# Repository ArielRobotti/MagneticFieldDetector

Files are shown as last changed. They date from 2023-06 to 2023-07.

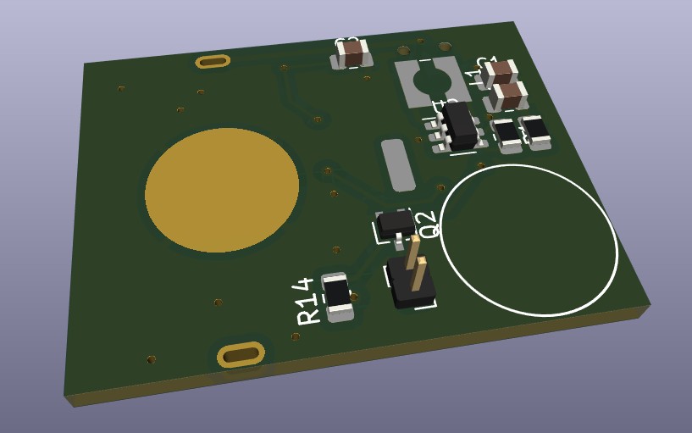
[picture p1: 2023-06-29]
images/ScreenShot_20230629164734.jpeg

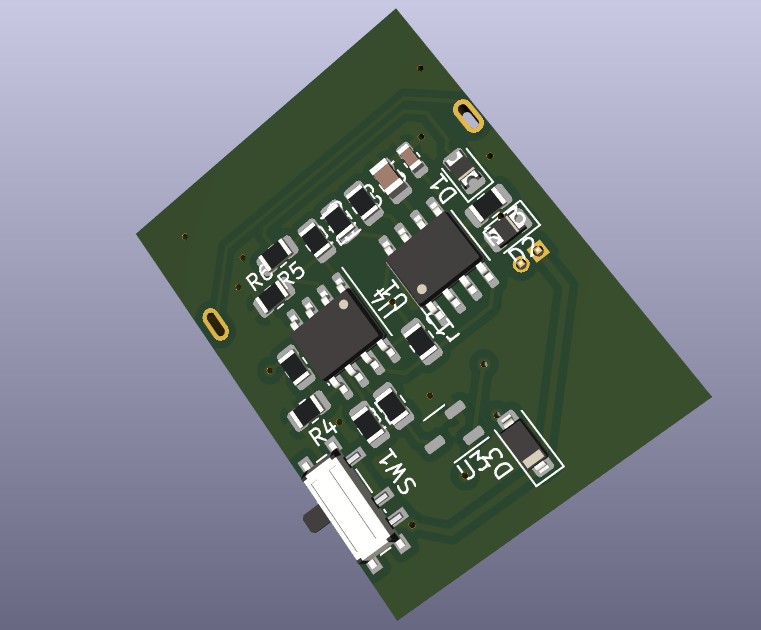
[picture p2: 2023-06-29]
images/ScreenShot_20230629164644.jpeg

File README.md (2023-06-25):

# Magnetic Field Polarity Detector 
## This device is designed for use in the field of magical arts.

## Description
The Magnetic Field Polarity Detector is a compact device designed to detect the presence of a magnetic field and indicate its polarity through vibrations. When the device is exposed to a north-to-south magnetic field, it will vibrate intermittently, while a south-to-north magnetic field will cause continuous vibrations.

## Schematic Design and Simulation in Multisim 14
The chosen design is based on the implementation of a linear Hall sensor, AH49E, which provides an output voltage proportional to the intensity of the magnetic field. The sensor outputs a voltage within specific thresholds depending on the magnetic field intensity. This voltage is then processed by comparators to activate the vibration motor accordingly.

### Design Adaptations
To accommodate the power supply requirements of the circuit components, an additional boost converter stage was included. This stage provides a stable 5V output from the 3V battery. The motor is directly powered from the 3V line to prevent feedback into the 5V line.

## Usage
1. Ensure that the device is turned off before use.
2. Insert a 3V battery into the battery holder.
3. Turn on the device using the power switch.
4. Hold the Magnetic Field Polarity Detector near the target area.
5. Observe the vibration patterns:
- Intermittent vibrations indicate the presence of a magnetic field in the south-to-north direction.
- Continuous vibrations indicate the presence of a magnetic field in the north-to-south direction.
6. Move the detector away from the proximity of the magnetic object to stop the vibrations.
7. Turn off the device when not in use to conserve battery life.
  
## Specifications
- Dimensions: 25mm x 30mm
- Power Supply: 3V battery (included)
- Power Switch: On/Off control

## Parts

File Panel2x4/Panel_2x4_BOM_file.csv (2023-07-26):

Comment | Designator | Footprint | LCSC Part Number
3Volts | BT1 | Batery Holder:cr1616
Motor_DC | M1 |  | C2685990
4u7 | C1 | C0805 | C2835535
4u7 | C2 | C0805 | C2835535
4u7 | C3 | C0805 | C2835535
4u7 | C5 | C0805 | C2835535
100n | C4 | 0603 | C342854
1N4148 | D1 | SOD-123 | C917030
1N4148 | D2 | SOD-123 | C917030
SS14HE | D3 | SOD-123HE | C4749020
4.7uH | L1 | SMD | 4x4mm | C5120868
BSS214NW | Q2 | SOT-323 | C3247496
910k | R1 | R0805 | C3016845
910k | R13 | R0805 | C3016845
100K | R2 | R0805 | C3017875
120k | R3 | R0805 | C268319
120k | R6 | R0805 | C268319
100k | R4 | R0805 | C3017875
100k | R5 | R0805 | C3017875
10k | R7 | R0805 | C3016734
10k | R8 | R0805 | C3016734
10k | R11 | R0805 | C3016734
10k | R12 | R0805 | C3016734
1k | R9 | R0805 | C3017842
22k | R10 | R0805 | C2889807
10 | R14 | R0805 | C101420
On | SW1 | SW_SPDT_PCM12 | C493292
SE555D | U1 | SO:SOIC-8 | C7593
TPS61070 | U2 | SOT-23-6 | C9841
49E Hall | U3 | SOT-23 | C85573
LM393 | U4 | SO:SOIC-8 | C2931601

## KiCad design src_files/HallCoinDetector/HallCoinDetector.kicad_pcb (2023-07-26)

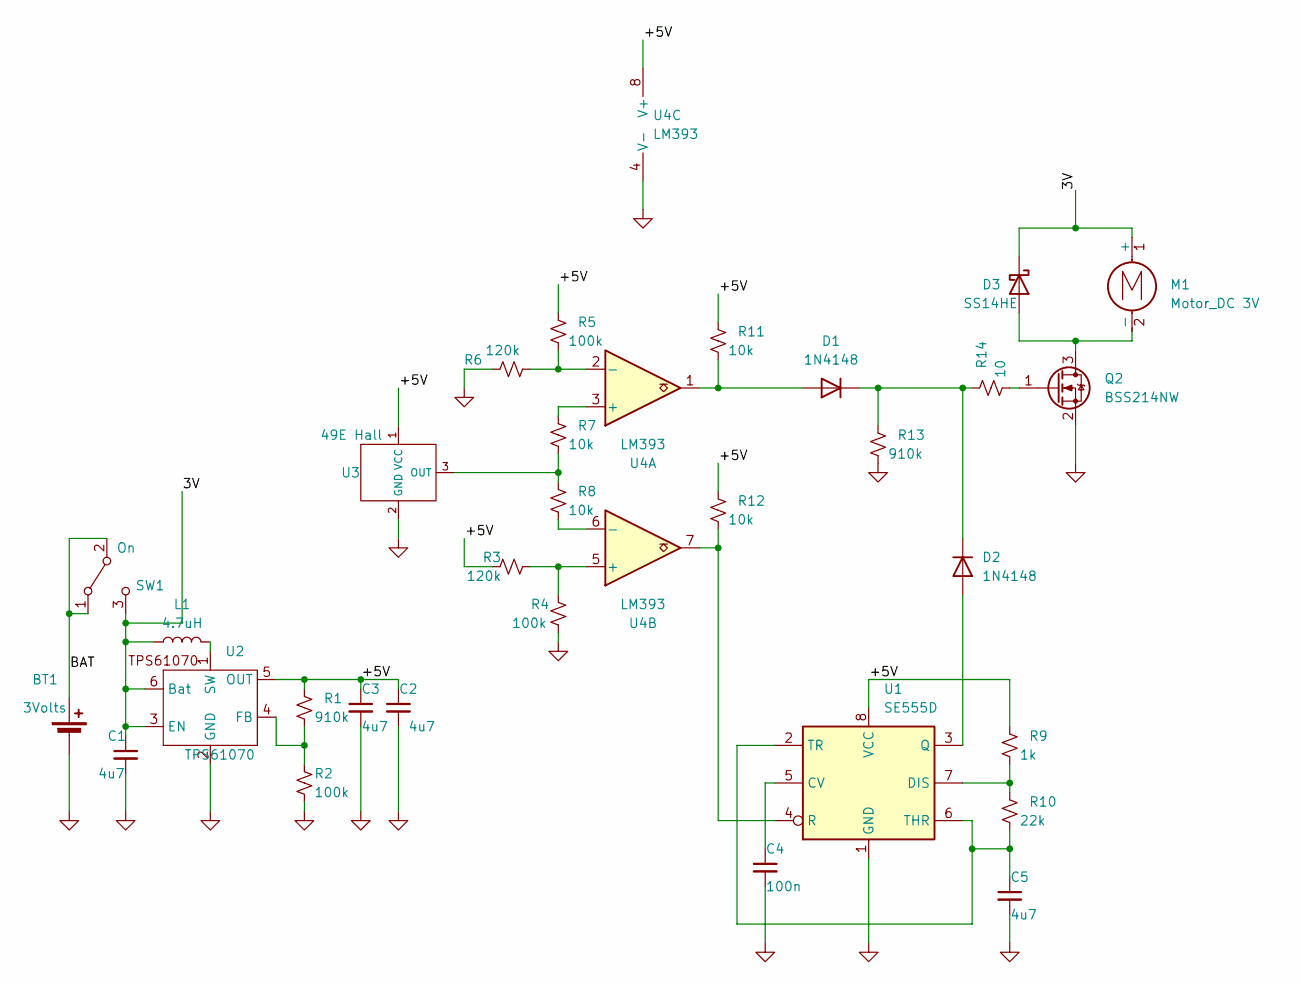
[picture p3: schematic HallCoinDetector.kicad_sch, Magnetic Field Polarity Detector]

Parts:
BT1: 3Volts; cr1616
C1, C2, C3, C5: 4u7; C_0805_2012Metric
C4: 100n; C_0603_1608Metric
D1, D2: 1N4148; D_SOD-123
D3: SS14HE; D_PowerDI-123
L1: 4.7uH; L_Wuerth_WE-TPC-3816
M1: Motor_DC 3V; PinHeader_1x02_P1.27mm_Vertical
Q2: BSS214NW; SOT-323_SC-70
R1, R13: 910k; R_0805_2012Metric
R2, R4, R5: 100k; R_0805_2012Metric
R3, R6: 120k; R_0805_2012Metric
R7, R8, R11, R12: 10k; R_0805_2012Metric
R9: 1k; R_0805_2012Metric
R10: 22k; R_0805_2012Metric
R14: 10; R_0805_2012Metric
SW1: On; SW_SPDT_PCM12
U1: SE555D; SOIC-8_3.9x4.9mm_P1.27mm
U2: TPS61070; SOT-23-6
U3: 49E Hall; SOT-23-3
U4: LM393; SOIC-8_3.9x4.9mm_P1.27mm

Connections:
/3V: C1.1, D3.1 (K), L1.1, M1.1 (+), SW1.3 (C), U2.3 (EN), U2.6 (Bat)
/+5V: C2.1, C3.1, R1.1, R3.1, R5.1, R9.1, R11.1, R12.1, U1.8 (VCC), U2.5 (OUT), U3.1 (VCC), U4.8 (V+)
/BAT: BT1.1 (+), SW1.1 (A), SW1.2 (B)
GND: BT1.2 (-), C1.2, C2.2, C3.2, C4.2, C5.2, Q2.2 (S), R2.2, R4.2, R6.1, R13.2, U1.1 (GND), U2.2 (GND), U3.2 (GND), U4.4 (V-)
unnamed: D1.2 (A), R11.2, U4.1
unnamed: D1.1 (K), D2.1 (K), R13.1, R14.1
unnamed: D2.2 (A), U1.3 (Q)
unnamed: D3.2 (A), M1.2 (-), Q2.3 (D)
unnamed: Q2.1 (G), R14.2
unnamed: C4.1, U1.5 (CV)
unnamed: R9.2, R10.1, U1.7 (DIS)
unnamed: R12.2, U1.4 (R), U4.7
unnamed: C5.1, R10.2, U1.2 (TR), U1.6 (THR)
unnamed: R1.2, R2.1, U2.4 (FB)
unnamed: L1.2, U2.1 (SW)
unnamed: R7.2, R8.1, U3.3 (OUT)
unnamed: R7.1, U4.3 (+)
unnamed: R5.2, R6.2, U4.2 (-)
unnamed: R3.2, R4.1, U4.5 (+)
unnamed: R8.2, U4.6 (-)

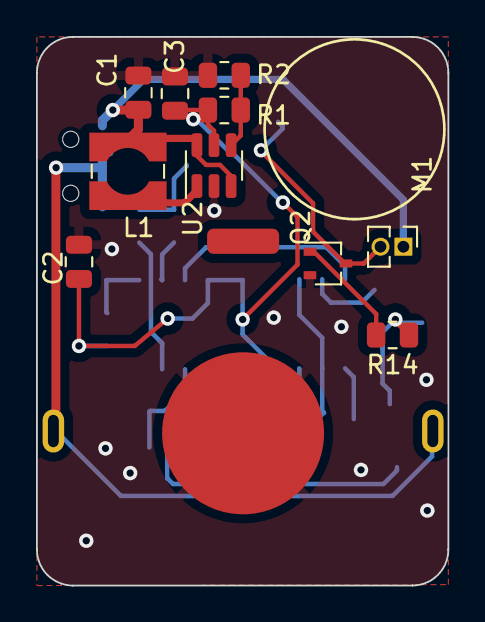
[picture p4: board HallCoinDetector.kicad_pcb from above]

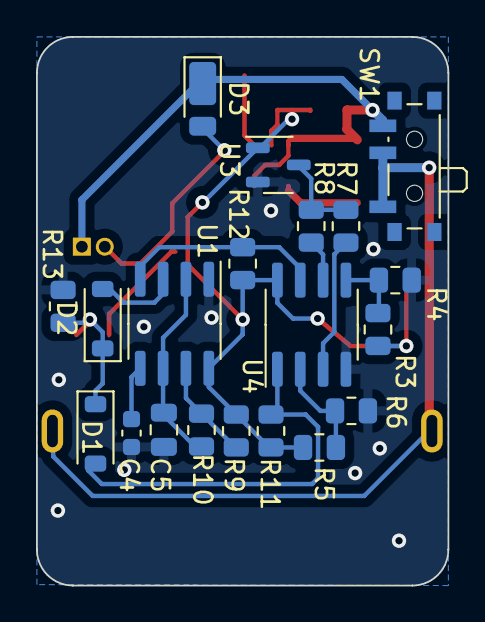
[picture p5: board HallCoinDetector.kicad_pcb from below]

Board: 2 copper layers, 22.9 x 30.5 mm, 31 parts (20 on the bottom side), 20 nets.

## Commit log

2023-06-28 diseño de librerias y ubicación de componentes
    [HallCoinDetector.kicad_pcb, HallCoinDetector.kicad_sch]
2023-06-29 Gerber files
    [HallCoinDetector-B_Cu.gbr, HallCoinDetector-B_Mask.gbr, HallCoinDetector-B_Paste.gbr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]
